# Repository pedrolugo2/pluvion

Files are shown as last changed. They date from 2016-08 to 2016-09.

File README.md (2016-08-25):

PLUVI.ON
--------

Como bons paulistanos, passamos pela mesma situação todos os anos. Chega dezembro, o céu escurece, a gente ouve um trovão lá no fundo, já dá aquele gelo na espinha pq a gente sabe que vem uma tempestade e provavelmente uma enchente por aí... E esse tipo de problema não acontece só em SP. 

Se olharmos Brasil, existem aproximadamente **30 milhões de brasileiros** expostos ao risco de enchentes e inundações. Além disso, existe uma projeção de impacto financeiro, onde as potenciais perdas anuais podem chegar a **4 bilhões de dólares até 2030** *(Fonte: Swiss Re)*

Olhando pra esse cenário alarmante, pensamos:
 “Vamos tentar resolver essa %$#@?” Se não para resolver totalmente, pelo menos entregar mais informação, mais inteligência para que a população possa se prevenir nesses eventos?
Resolvemos juntar nosso conhecimento de hardware e software e mergulhamos nesse mundo e logo de cara demos de cara com uma barreira: as dificuldades de conseguir informações sobre clima e chuva
Identificamos **3 principais desafios** relacionados à informação:

 1. As informações históricas são de difícil acesso ao cidadão comum (ou
    estão em mão de instituições privadas ou demandam muita burocracia
    dos órgãos públicos);
    
 2. Muitas delas são coletadas apenas no dia seguinte e portanto não auxiliam na
    prevenção 
    
 3. São informadas de forma genérica: “pode alagar a cidade de
    SP” – mas SP é grande demais para termos apenas essa informação. A
    probabilidade de alagar a Av. Paulista é sempre muito menor do que
    alagar a Av. Aricanduva

Foi a partir dessas hipóteses que construímos o Pluvi.On, uma estação meteorológica Open Source e de baixo custo para ser espalhada na maior quantidade de pontos da cidade que pudermos!!!

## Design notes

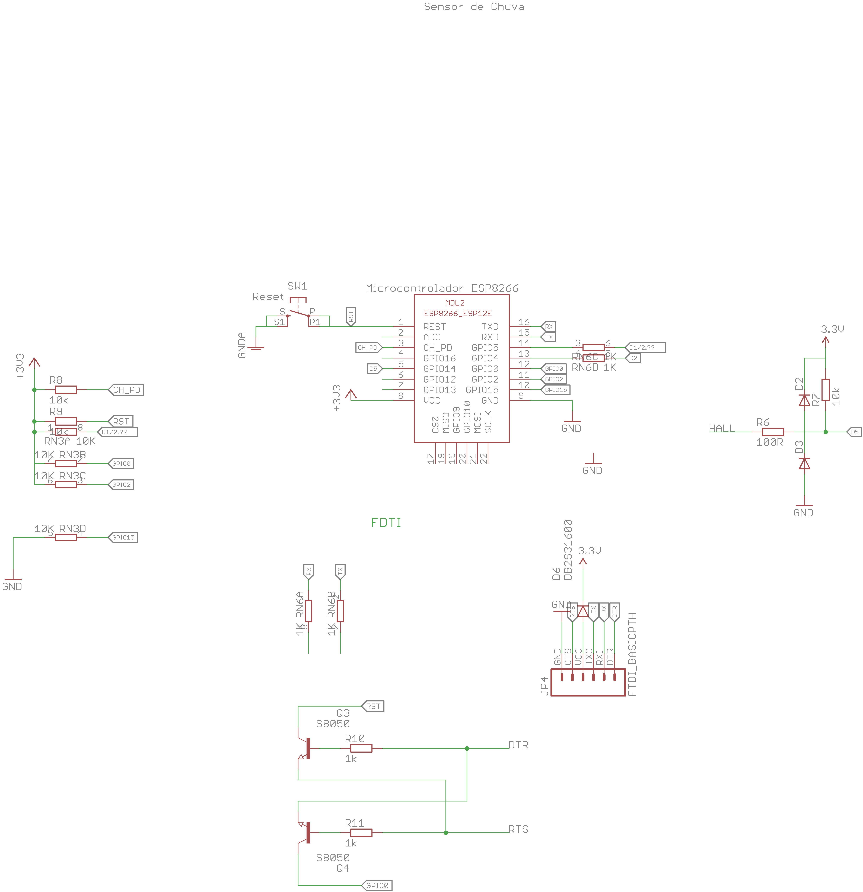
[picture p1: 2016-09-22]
Eletrônica/Principal/Pluvion 1 RevA_3.png

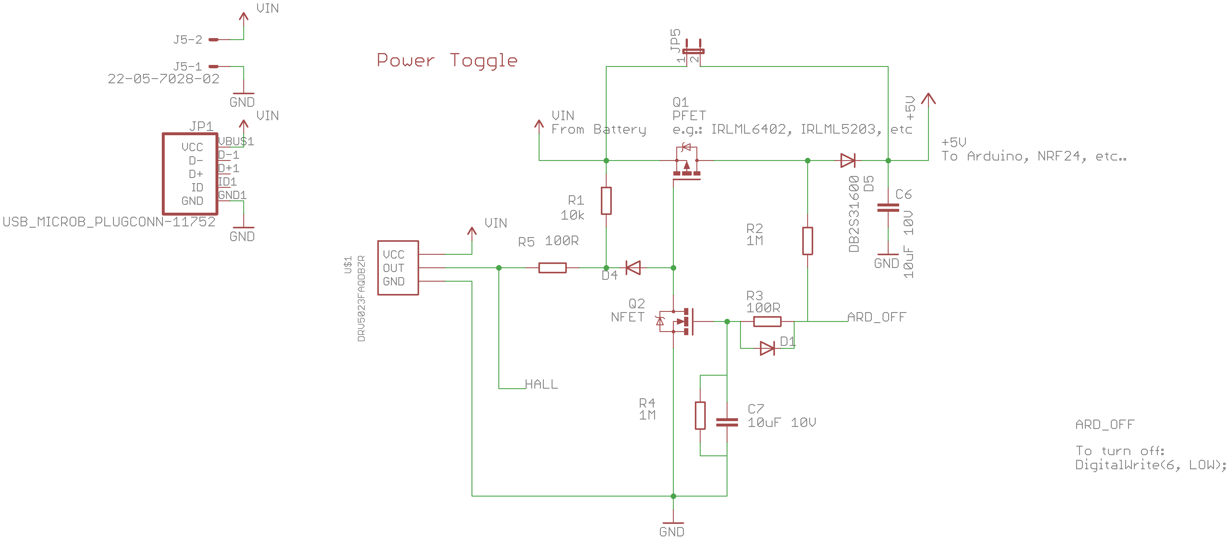
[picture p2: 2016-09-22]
Eletrônica/Principal/Pluvion 1 RevA_1.png

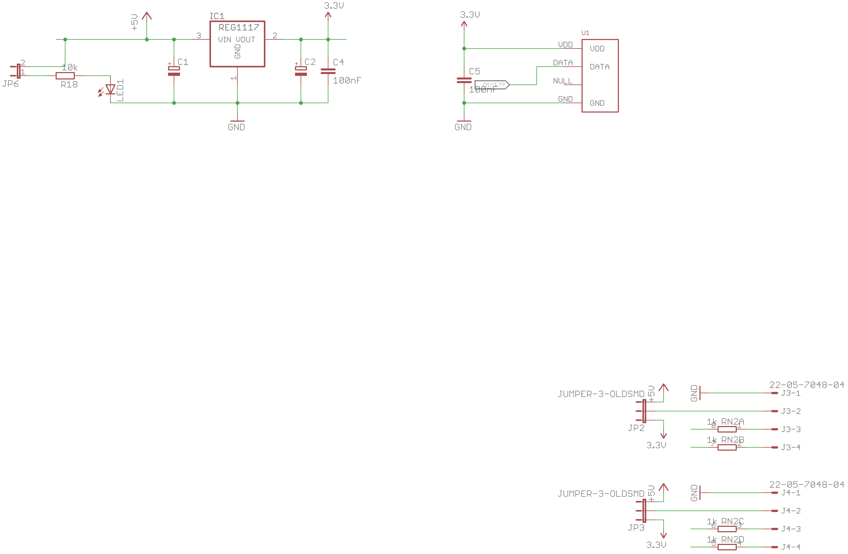
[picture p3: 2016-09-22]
Eletrônica/Principal/Pluvion 1 RevA_2.png

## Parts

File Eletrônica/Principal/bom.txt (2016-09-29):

Partlist exported from C:/Users/Pedro/Desktop/05. Krafty/XX. Projetos/Pluvi.On/residencia/Eletrônica/Principal/Pluvion 2.sch at 26/09/2016 10:45

Qty Value              Device                    Package            Parts      Description                   MF MPN OC_FARNELL OC_NEWARK PROD_ID    
2                      DIODESOD                  SOD-323            D1, D4     Diode                                                     DIO-09646  
1                      JUMPER-2PTH               1X02               JP5        Jumper                                                               
1                      R-EU_R0805                R0805              R6         RESISTOR, European symbol                                            
1                      RHT03_DHT-22_AM2302RA     RHT03_DHT-22/RA    U1         RHT03 / DHT-22 / AM2302                                   SEN-10167  
2   100R               R-EU_R0805                R0805              R3, R5     RESISTOR, European symbol                                            
1   10k                R-EU_R0805                R0805              R1         RESISTOR, European symbol                                            
3   10uF 10V           C-EUC0805                 C0805              C1, C6, C7 CAPACITOR, European symbol                                           
2   1M                 R-EU_R0805                R0805              R2, R4     RESISTOR, European symbol                                            
1   22-05-7028-02      22-05-7028-02             7395-02            J1         CONNECTOR                            9731601    unknown              
1   DB2S31600          DIODESMA                  SMA-DIODE          D5         Diode                                                                
1   DRV5023FAQDBZR     DRV5023FAQDBZR            SOT23              U$1        Digital Switch Hall Sensor                                           
1   NFET               MOSFET-NCHANNELBSS123LT1G SOT23              Q2         Common NMOSFET Parts                                      TRANS-08345
1   NODE-LOLIN-ESP8266 NODE-LOLIN-ESP8266        NODE-LOLIN-ESP8266 U$2                                                                             
1   PFET               IRLML5203                 MICRO3             Q1         HEXFET P-Channel Power MOSFET

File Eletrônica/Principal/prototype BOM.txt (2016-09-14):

Partlist exported from /Users/wes/Google Drive/trab/redbull/Residencia Basement/repo/Pluvion/Eletrônica/Principal/Pluvion 1 - Rev A.sch at 9/14/16 01:56

Assembly variant: ''

Qty Value                     Device                    Parts              
OK 2                             CPOL-EUC                  C1, C2             
OKISH 4                             DIODESOD                  D1, D2, D3, D4     
              
1                             JUMPER-2PTH               JP5                
                
1                             LED1206                   LED1               

1   1k                        4R-N0603-ARV              RN6, RN2   http://www.opoeneletronica.com.br/home/produto/codigo:12739/rede-resistiva-1k-0603-1608-smd-4res-superficie-rede-resistiva-5
1   10k                       4R-N0603-ARV              RN3    http://www.opoeneletronica.com.br/home/produto/codigo:12686/rede-resistiva-10k-0603-1608-smd-4res-superficie-rede-resistiva-5

OK 3   100R                      R-EU_R0805                R3, R5, R6
OK 2   1M                        R-EU_R0805                R2, R4    
OK 2   1k                        R-EU_R0805                R10, R11                          
OK 5   10k                       R-EU_R0805                R1, R7, R8, R9, R18

OK 2   10uF 10V                  C-EUC0805                 C6, C7 
OK 2   100nF                     C-EUC0805                 C4, C5

OK 2   DB2S31600                 DIODESMA                  D5, D6

1   DRV5023FAQDBZR            DRV5023FAQDBZR            U$1 

OK 1   NFET                      MOSFET-NCHANNELBSS123LT1G Q2                 
OK 1   PFET                      IRLML5203                 Q1                 
1   REG1117                   REG1117                   IC1  http://www.opoeneletronica.com.br/home/produto/codigo:14194/lm1117-3-3v-sot223-smd-superficie

1   Reset                     10-XX-4.5SMD              SW1 

OK 2   S8050                     NPN-TRANSISTOR_SOT23      Q3, Q4

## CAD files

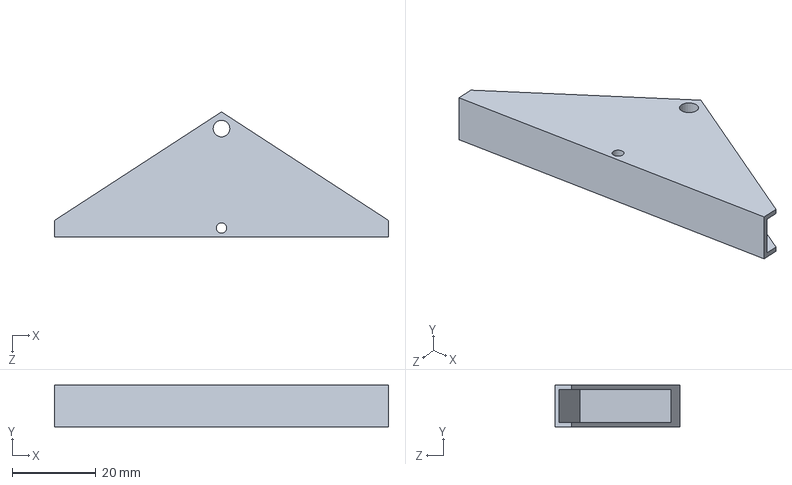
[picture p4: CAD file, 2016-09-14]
Mecânica/Bucket/Bucket.SLDPRT
80.0 x 10.0 x 30.0 mm

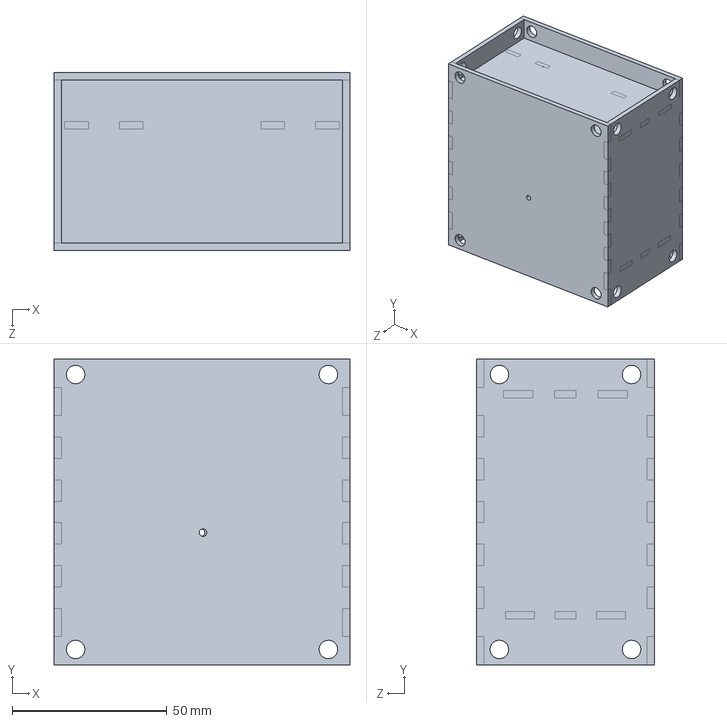
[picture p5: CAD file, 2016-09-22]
Mecânica/Montagem Pluvi.on - SW.SLDPRT
95.7 x 98.9 x 57.5 mm

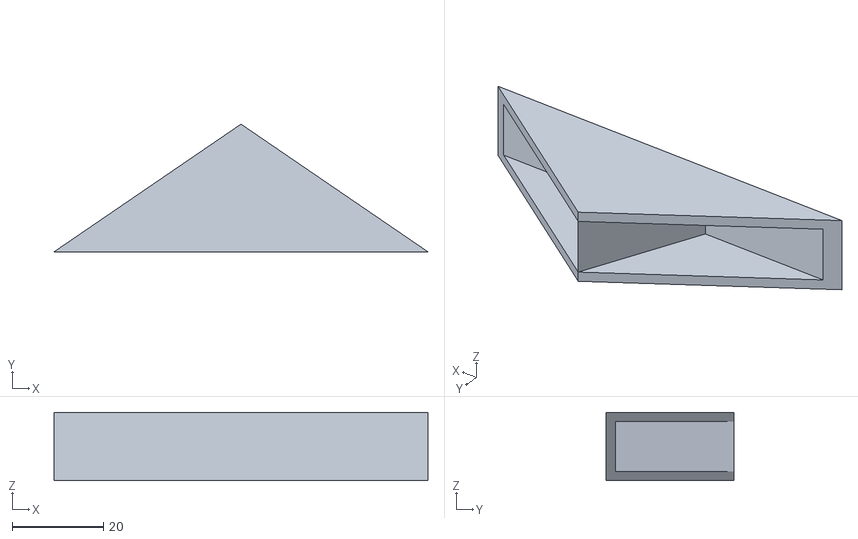
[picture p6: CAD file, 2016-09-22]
Mecânica/Pluvi.on - Triangulo volume stl.STL
82.0 x 28.0 x 15.0

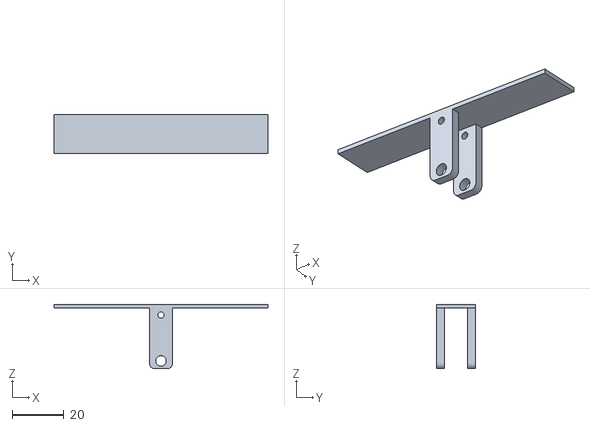
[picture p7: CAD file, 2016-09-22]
Mecânica/Base.stl
83.0 x 15.0 x 25.0

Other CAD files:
Mecânica/Bucket/Bucket.STL
Mecânica/Montagem Pluvi.on - SW.STL

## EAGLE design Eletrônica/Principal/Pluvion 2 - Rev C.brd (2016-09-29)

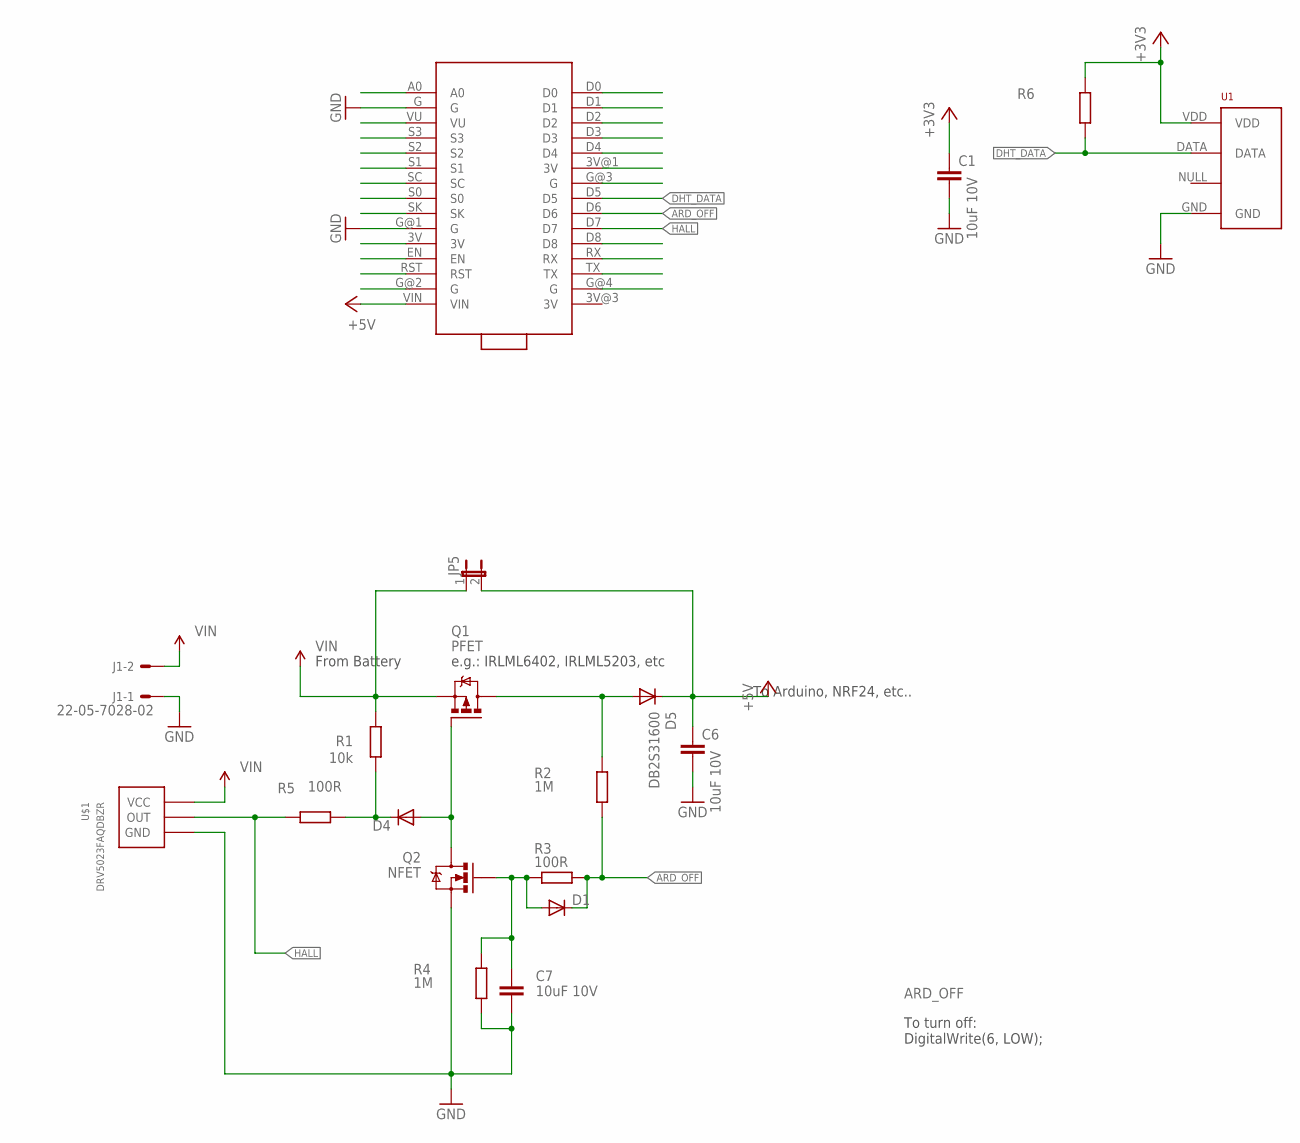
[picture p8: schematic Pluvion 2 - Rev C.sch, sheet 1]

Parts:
C1, C6, C7: 10uF 10V; C0805
D1, D4: DIODESOD; SOD-323
D5: DB2S31600; SMA-DIODE
J1: 22-05-7028-02; 7395-02
JP5: JUMPER-2PTH; 1X02
Q1: PFET; MICRO3
Q2: NFET; SOT23
R1: 10k; R0805
R2, R4: 1M; R0805
R3, R5: 100R; R0805
R6: R-EU_R0805; R0805
U1: RHT03_DHT-22_AM2302RA; RHT03_DHT-22/RA
U$1: DRV5023FAQDBZR; SOT23
U$2: NODE-LOLIN-ESP8266

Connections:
+3V3: C1.1, R6.2, U1.VDD, U$2.3V@1 (3V)
+5V: C6.1, D5.C, JP5.2, U$2.VIN
ARD_OFF: D1.1 (C), R2.1, R3.2, U$2.D6
BUTTONS: D4.2 (A), Q1.1 (G), Q2.3 (D)
DHT_DATA: R6.1, U1.DATA, U$2.D5
GND: C1.2, C6.2, C7.2, J1.1, Q2.2 (S), R4.1, U1.GND, U$1.3 (GND), U$2.G, U$2.G@1 (G)
HALL: R5.2, U$1.2 (OUT), U$2.D7
unnamed: D5.A, Q1.3 (D), R2.2
unnamed: C7.1, D1.2 (A), Q2.1 (G), R3.1, R4.2
unnamed: D4.1 (C), R1.1, R5.1
VIN: J1.2, JP5.1, Q1.2 (S), R1.2, U$1.1 (VCC)

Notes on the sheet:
e.g.: IRLML6402, IRLML5203, etc
To Arduino, NRF24, etc..
To turn off: DigitalWrite(6, LOW);
From Battery

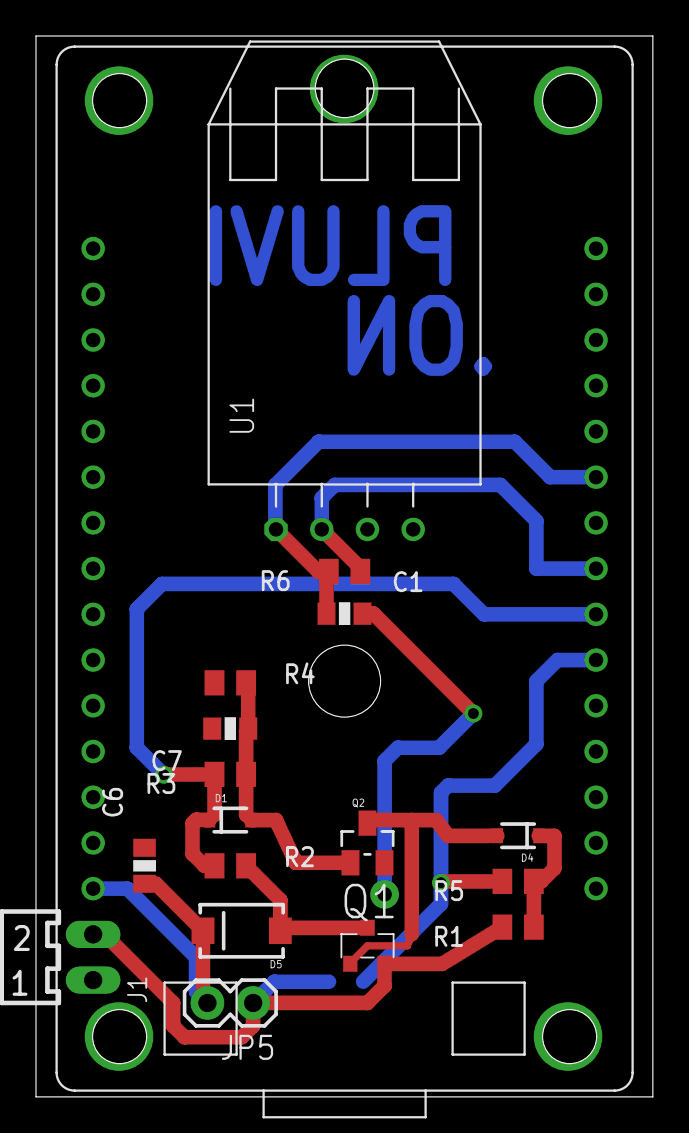
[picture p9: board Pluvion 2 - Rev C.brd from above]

Board: 2 copper layers, 34.3 x 58.9 mm, 19 parts (1 on the bottom side), 11 nets.

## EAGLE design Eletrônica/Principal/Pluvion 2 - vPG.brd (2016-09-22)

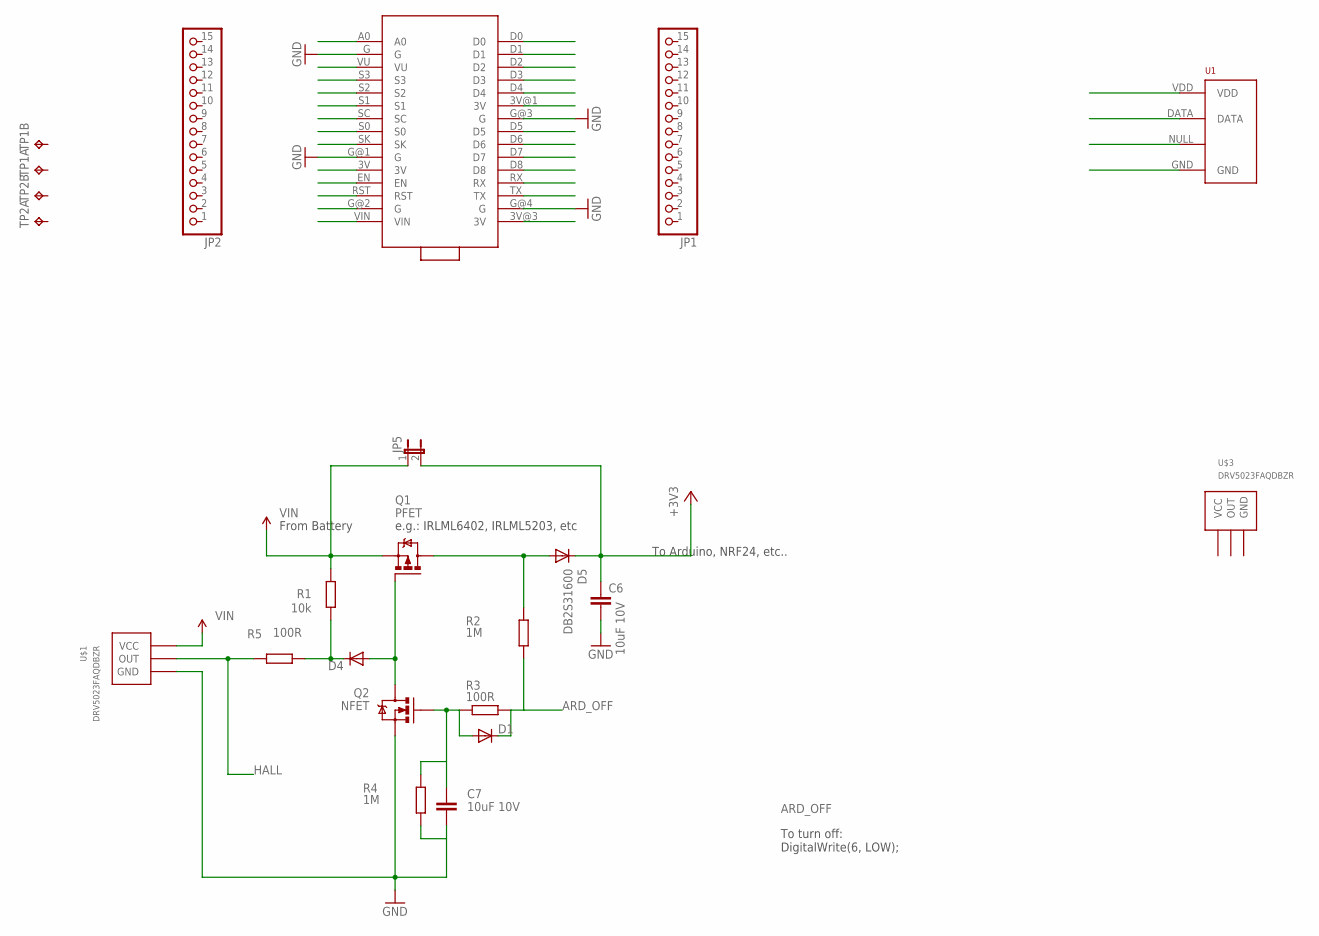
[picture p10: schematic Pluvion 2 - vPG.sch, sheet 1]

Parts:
C6, C7: 10uF 10V; C0805
D1, D4: DIODESMB; SMB-DIODE
D5: DB2S31600; SMB-DIODE
JP1, JP2: PINHD-1X15; 1X15
JP5: JUMPER-2PTH; 1X02
Q1: PFET; MICRO3
Q2: NFET; SOT23
R1: 10k; R0805
R2, R4: 1M; R0805
R3, R5: 100R; R0805
TP1, TP2: TP2P2-38-17; P2-38-17
U1: RHT03_DHT-22_AM2302RA; RHT03_DHT-22/RA
U$1, U$3: DRV5023FAQDBZR; SOT23
U$2: NODE-LOLIN-ESP8266

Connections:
+3V3: C6.1, D5.C, JP5.2
ARD_OFF: D1.C, R2.1, R3.2
BUTTONS: D4.A, Q1.1 (G), Q2.3 (D)
GND: C6.2, C7.2, Q2.2 (S), R4.1, U$1.3 (GND), U$2.G, U$2.G@1 (G), U$2.G@3 (G), U$2.G@4 (G)
HALL: R5.2, U$1.2 (OUT)
unnamed: D5.A, Q1.3 (D), R2.2
unnamed: C7.1, D1.A, Q2.1 (G), R3.1, R4.2
unnamed: D4.C, R1.1, R5.1
VIN: JP5.1, Q1.2 (S), R1.2, U$1.1 (VCC)

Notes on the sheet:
e.g.: IRLML6402, IRLML5203, etc
To Arduino, NRF24, etc..
To turn off: DigitalWrite(6, LOW);
From Battery

Board: 2 copper layers, 21 parts (0 on the bottom side), 9 nets, no tracks yet.

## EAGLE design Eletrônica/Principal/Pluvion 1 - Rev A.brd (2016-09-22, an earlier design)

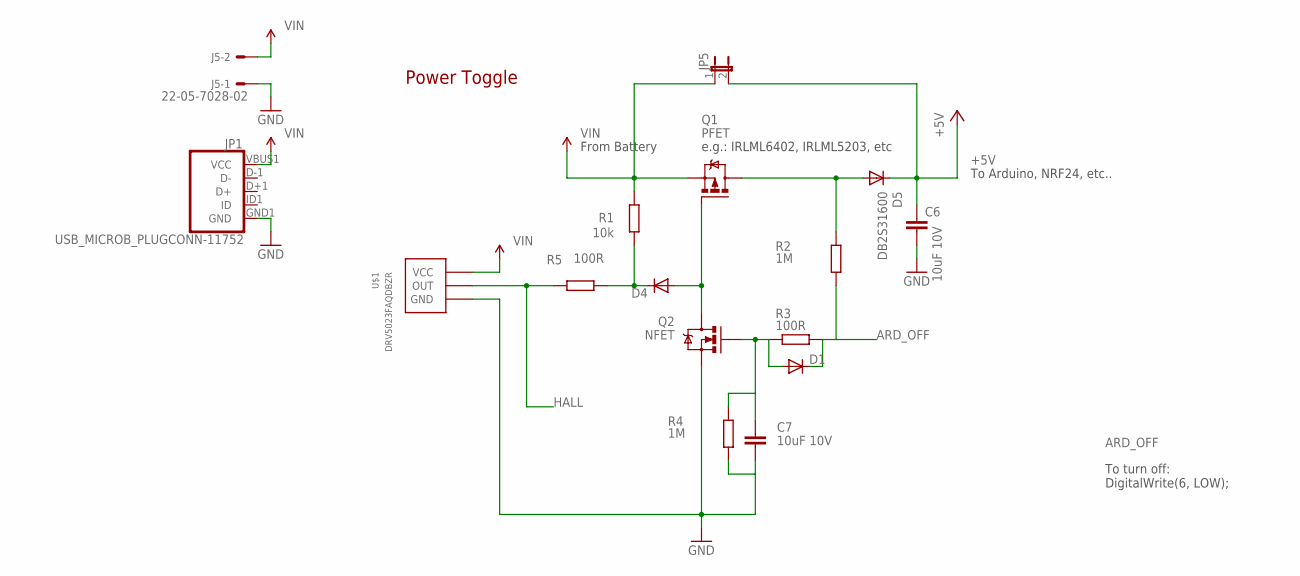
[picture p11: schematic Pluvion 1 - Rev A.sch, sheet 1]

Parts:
C6, C7: 10uF 10V; C0805
D1, D4: DIODESOD; SOD-323
D5: DB2S31600; SMA-DIODE
J5: 22-05-7028-02; 7395-02
JP1: USB_MICROB_PLUGCONN-11752; USB-B-MICRO-SMD_V03
JP5: JUMPER-2PTH; 1X02
Q1: PFET; MICRO3
Q2: NFET; SOT23
R1: 10k; R0805
R2, R4: 1M; R0805
R3, R5: 100R; R0805
U$1: DRV5023FAQDBZR; SOT23

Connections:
+5V: C6.1, D5.C, JP5.2; also elsewhere on the board
ARD_OFF: D1.1 (C), R2.1, R3.2
BUTTONS: D4.2 (A), Q1.1 (G), Q2.3 (D)
GND: C6.2, C7.2, J5.1, JP1.GND1 (GND), Q2.2 (S), R4.1, U$1.3 (GND); also elsewhere on the board
HALL: R5.2, U$1.2 (OUT); also elsewhere on the board
unnamed: D5.A, Q1.3 (D), R2.2
unnamed: C7.1, D1.2 (A), Q2.1 (G), R3.1, R4.2
unnamed: D4.1 (C), R1.1, R5.1
VIN: J5.2, JP1.VBUS1 (VCC), JP5.1, Q1.2 (S), R1.2, U$1.1 (VCC)

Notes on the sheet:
e.g.: IRLML6402, IRLML5203, etc
To Arduino, NRF24, etc..
To turn off: DigitalWrite(6, LOW);
From Battery
Power Toggle

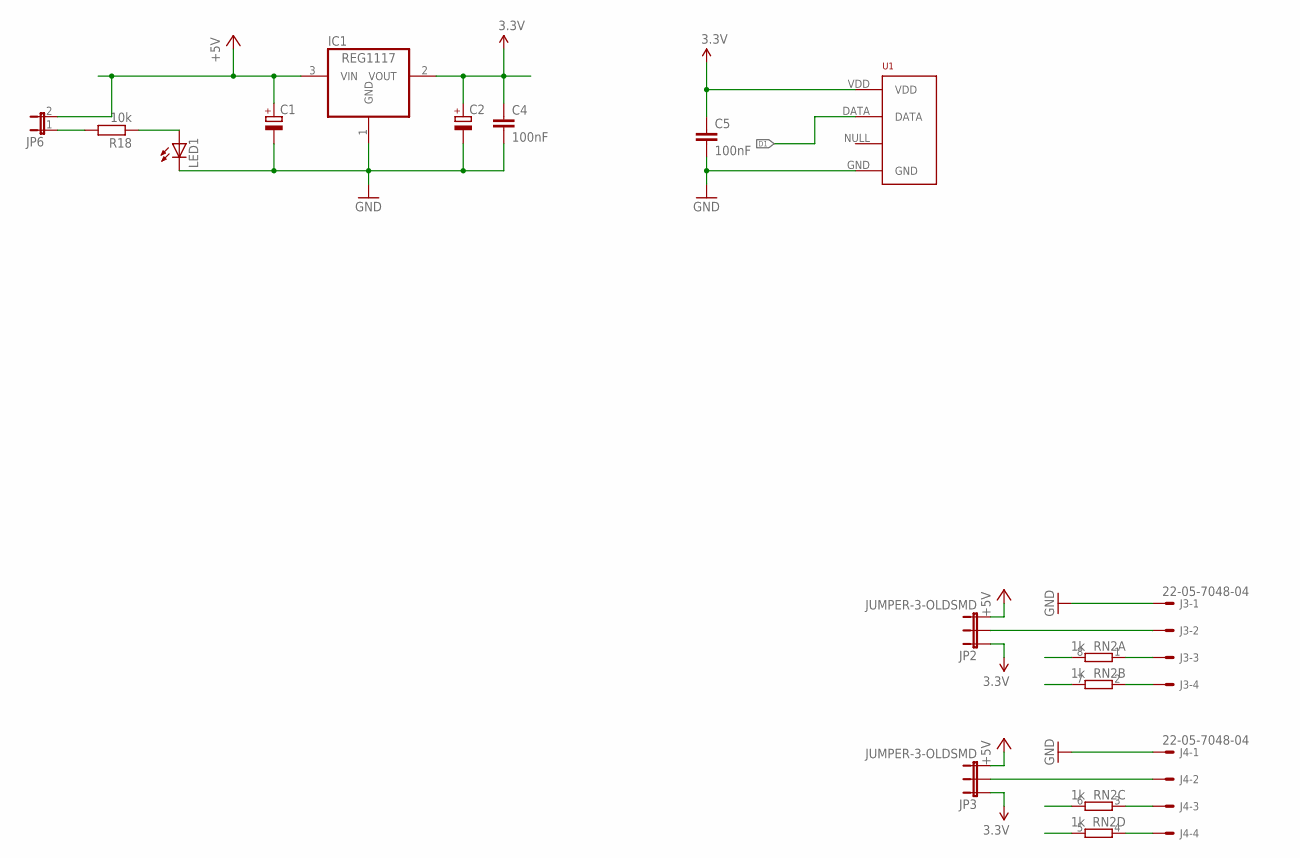
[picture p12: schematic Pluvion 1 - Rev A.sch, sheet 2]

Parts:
C1, C2: CPOL-EUC; PANASONIC_C
C4, C5: 100nF; C0805
IC1: REG1117; SOT223
J3, J4: 22-05-7048-04; 7395-04
JP2, JP3: JUMPER-3-OLDSMD; SJ_3
JP6: JUMPER-2SMD-NO; SJ_2S-NO
LED1: LED1206; LED-1206
R18: 10k; R0805
RN2: 1k; 0603-ARV
U1: RHT03_DHT-22_AM2302RA; RHT03_DHT-22/RA

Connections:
+3V3: C2.+, C4.1, C5.1, IC1.2 (VOUT), JP2.1, JP3.1, U1.VDD; also elsewhere on the board
+5V: C1.+, IC1.3 (VIN), JP2.3, JP3.3, JP6.2; also elsewhere on the board
D1: U1.DATA; also elsewhere on the board
GND: C1.-, C2.-, C4.2, C5.2, IC1.1 (GND), J3.1, J4.1, LED1.C, U1.GND; also elsewhere on the board
unnamed: J3.3, RN2.1
unnamed: J3.4, RN2.2 (1)
unnamed: J4.3, RN2.3 (1)
unnamed: J3.2, JP2.2
unnamed: J4.4, RN2.4 (1)
unnamed: J4.2, JP3.2
unnamed: LED1.A, R18.1
unnamed: JP6.1, R18.2

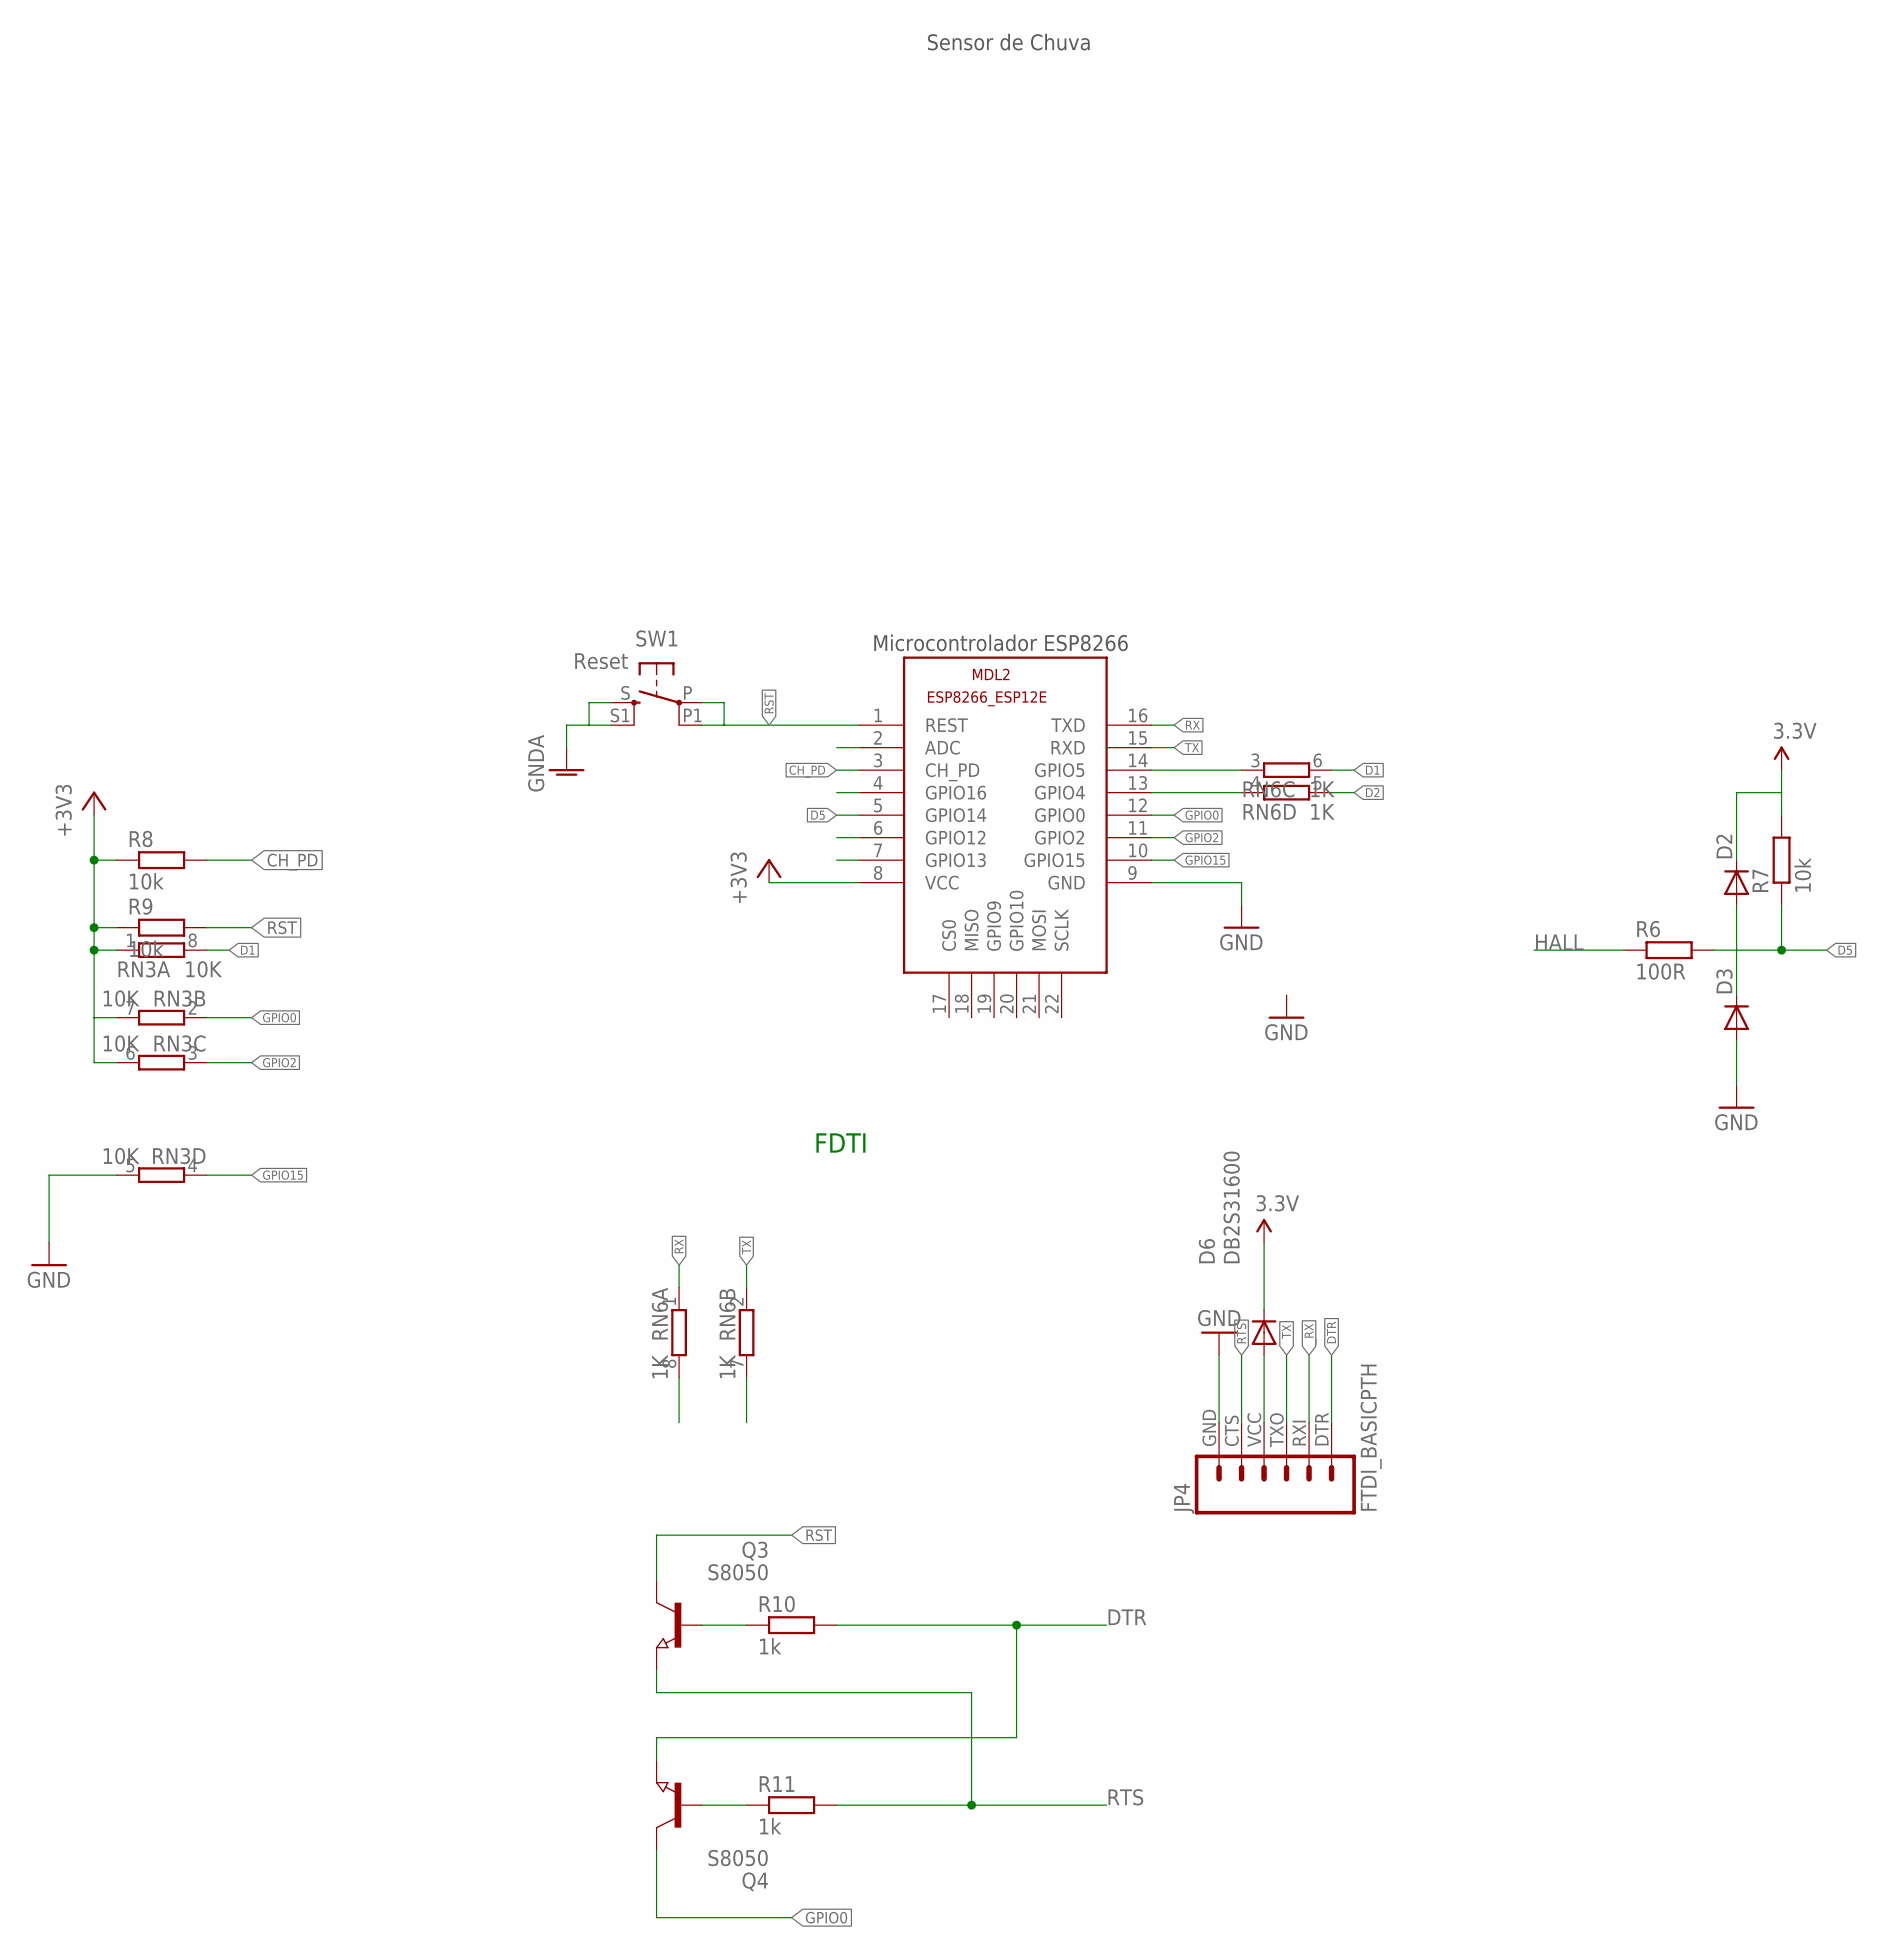
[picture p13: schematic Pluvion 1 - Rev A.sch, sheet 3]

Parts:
D2, D3: DIODESOD; SOD-323
D6: DB2S31600; SMA-DIODE
JP4: FTDI_BASICPTH; FTDI_BASIC
MDL2: ESP8266-12EESP8266-ESP12E; ESP8266-ESP12E
Q3, Q4: S8050; SOT23
R6: 100R; R0805
R7, R8, R9: 10k; R0805
R10, R11: 1k; R0805
RN3: 10K; 0603-ARV
RN6: 1K; 0603-ARV
SW1: Reset; BT4.5X4.5

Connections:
+3V3: D2.1 (C), D6.C, MDL2.8 (VCC), R7.2, R8.1, R9.1, RN3.1, RN3.6 (2), RN3.7 (2); also elsewhere on the board
CH_PD: MDL2.3 (CH_PD), R8.2
D1: RN3.8 (2), RN6.6 (2); also elsewhere on the board
D2: RN6.5 (2)
D5: D2.2 (A), D3.1 (C), MDL2.5 (GPIO14), R6.2, R7.1
DTR: JP4.DTR (1), Q4.2 (E), R10.2
GND: D3.2 (A), JP4.GND (6), MDL2.9 (GND), RN3.5 (2), SW1.S, SW1.S1; also elsewhere on the board
GPIO0: MDL2.12 (GPIO0), Q4.3 (C), RN3.2 (1)
GPIO2: MDL2.11 (GPIO2), RN3.3 (1)
GPIO15: MDL2.10 (GPIO15), RN3.4 (1)
HALL: R6.1; also elsewhere on the board
unnamed: Q3.1 (B), R10.1
unnamed: Q4.1 (B), R11.1
unnamed: MDL2.14 (GPIO5), RN6.3 (1)
unnamed: D6.A, JP4.VCC (4)
unnamed: MDL2.13 (GPIO4), RN6.4 (1)
RST: MDL2.1 (REST), Q3.3 (C), R9.2, SW1.P, SW1.P1
RTS: JP4.CTS (5), Q3.2 (E), R11.2
RX: MDL2.16 (TXD), RN6.1
TX: MDL2.15 (RXD), RN6.2 (1)
_RX: JP4.RXI (2), RN6.8 (2)
_TX: JP4.TXO (3), RN6.7 (2)

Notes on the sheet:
Sensor de Chuva
Microcontrolador ESP8266
FDTI

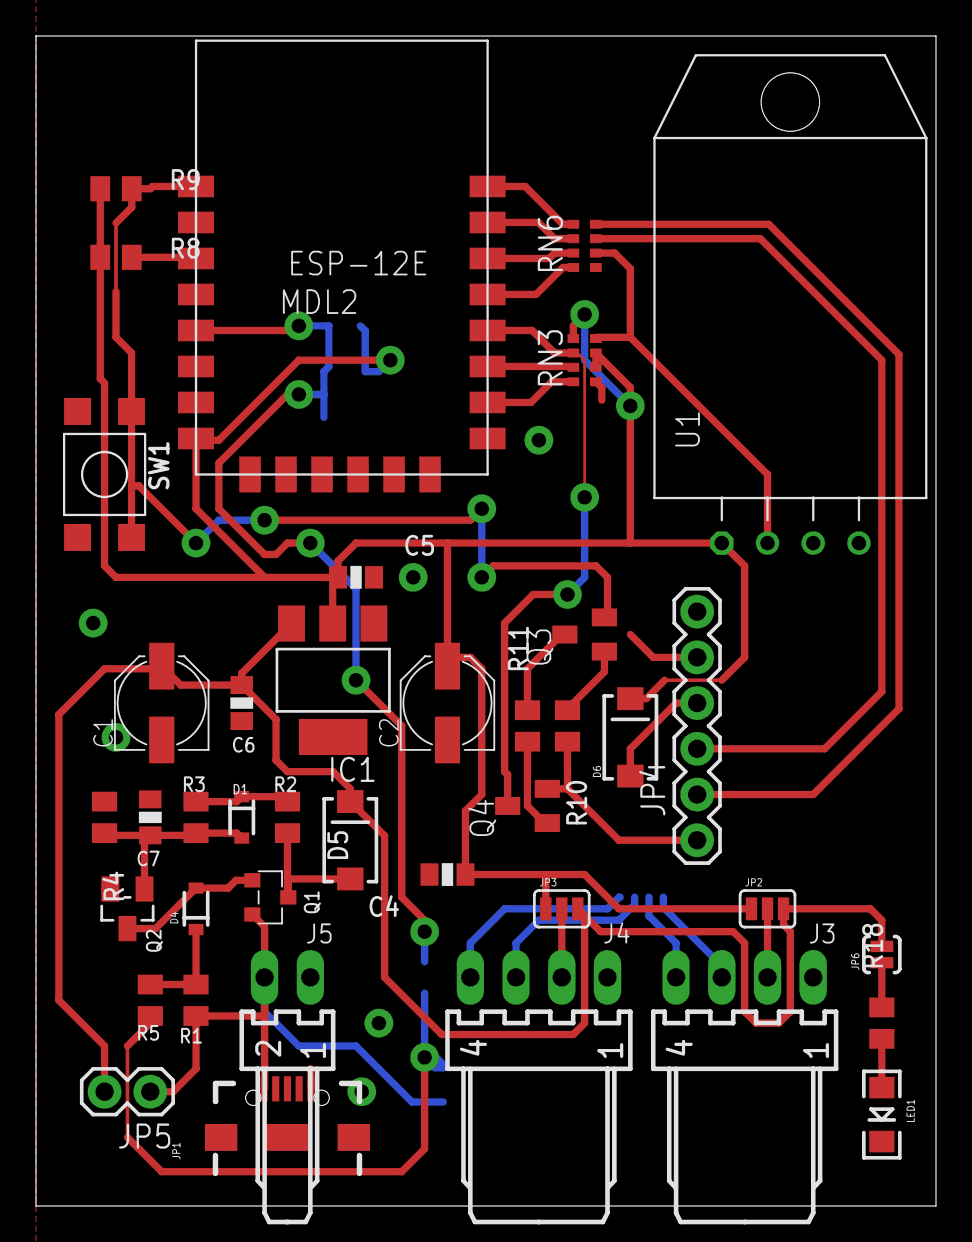
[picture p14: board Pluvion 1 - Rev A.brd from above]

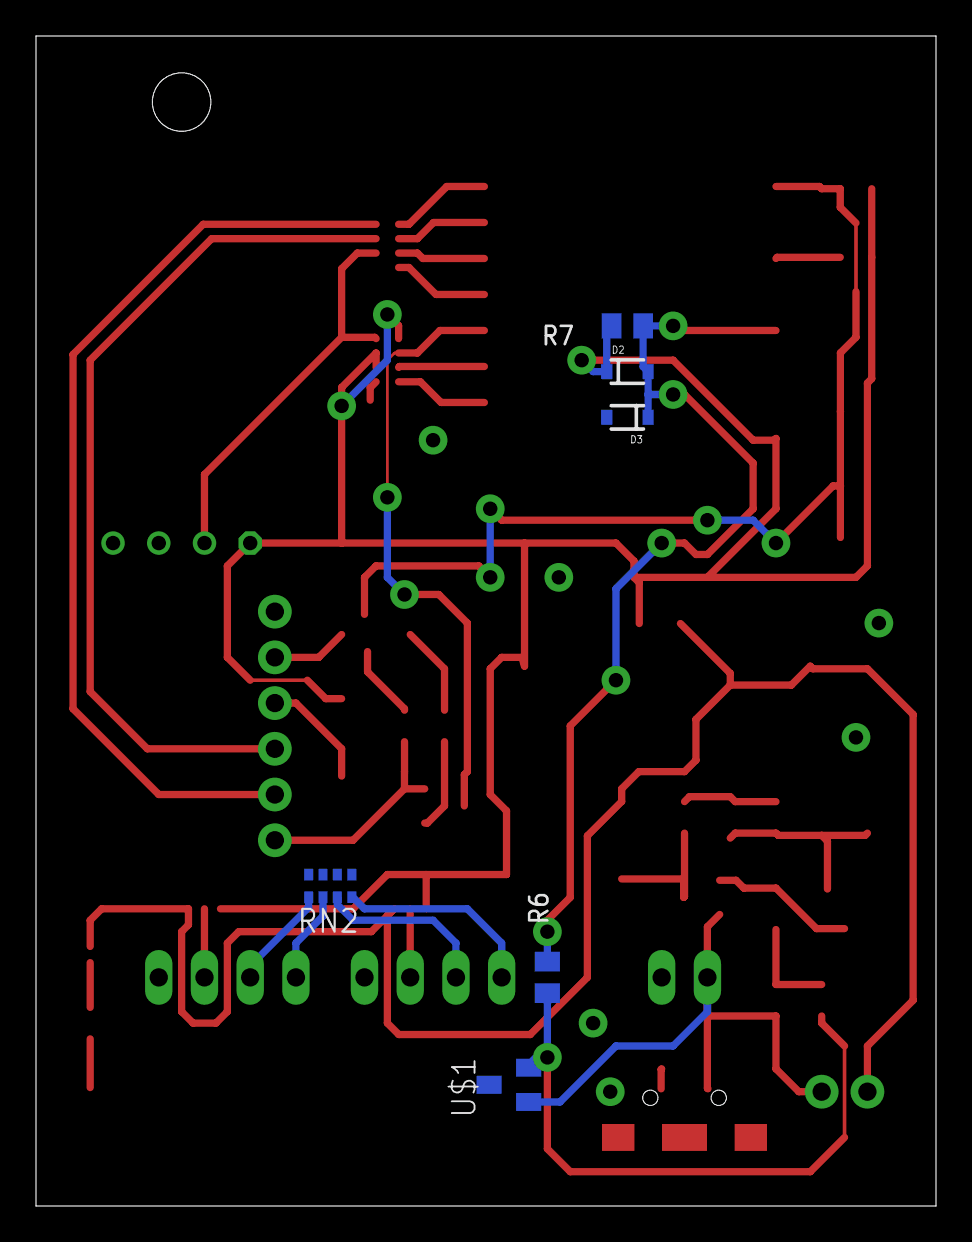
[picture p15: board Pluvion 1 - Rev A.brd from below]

Board: 2 copper layers, 50.0 x 65.0 mm, 46 parts (6 on the bottom side), 36 nets.

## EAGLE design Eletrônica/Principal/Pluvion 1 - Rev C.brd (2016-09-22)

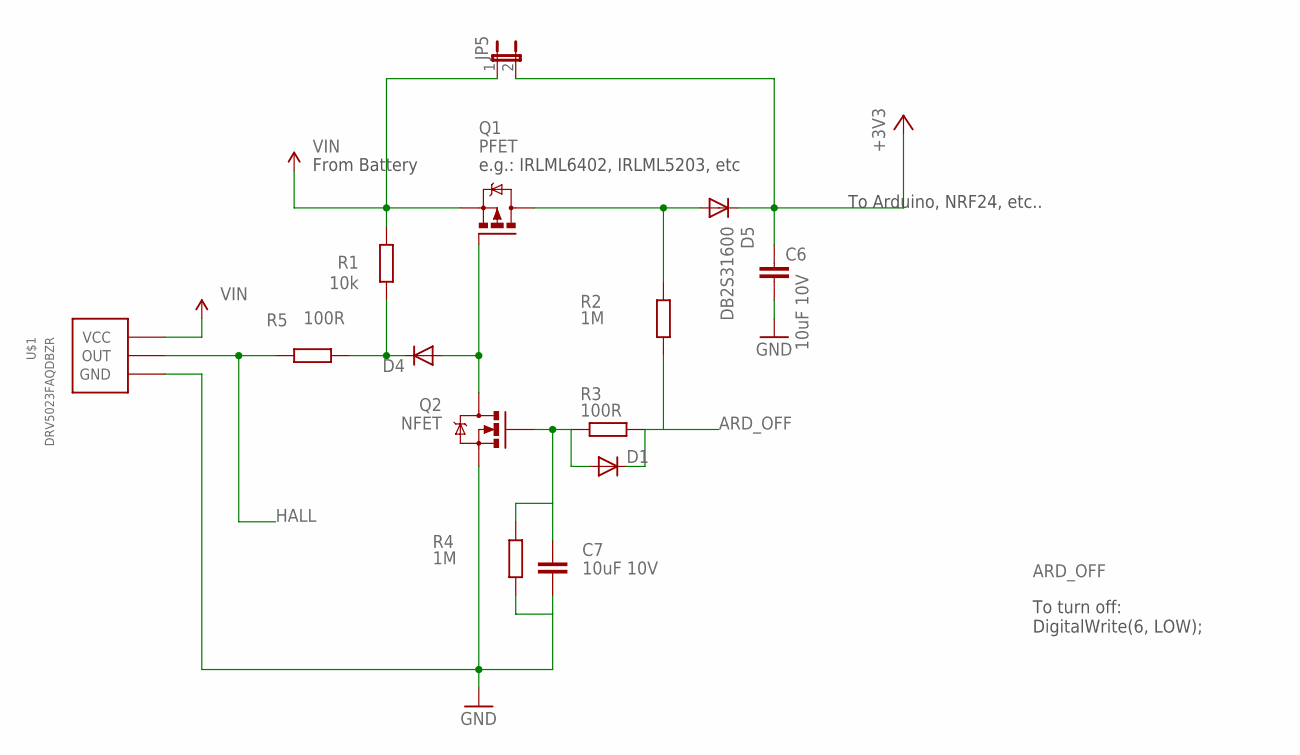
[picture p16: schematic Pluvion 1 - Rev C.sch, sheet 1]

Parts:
C6, C7: 10uF 10V; C0805
D1, D4: DIODESMB; SMB-DIODE
D5: DB2S31600; SMB-DIODE
JP5: JUMPER-2PTH; 1X02
Q1: PFET; MICRO3
Q2: NFET; SOT23
R1: 10k; R0805
R2, R4: 1M; R0805
R3, R5: 100R; R0805
U$1: DRV5023FAQDBZR; SOT23

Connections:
+3V3: C6.1, D5.C, JP5.2; also elsewhere on the board
ARD_OFF: D1.C, R2.1, R3.2; also elsewhere on the board
BUTTONS: D4.A, Q1.1 (G), Q2.3 (D)
GND: C6.2, C7.2, Q2.2 (S), R4.1, U$1.3 (GND); also elsewhere on the board
HALL: R5.2, U$1.2 (OUT)
unnamed: D5.A, Q1.3 (D), R2.2
unnamed: C7.1, D1.A, Q2.1 (G), R3.1, R4.2
unnamed: D4.C, R1.1, R5.1
VIN: JP5.1, Q1.2 (S), R1.2, U$1.1 (VCC)

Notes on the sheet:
e.g.: IRLML6402, IRLML5203, etc
To Arduino, NRF24, etc..
To turn off: DigitalWrite(6, LOW);
From Battery

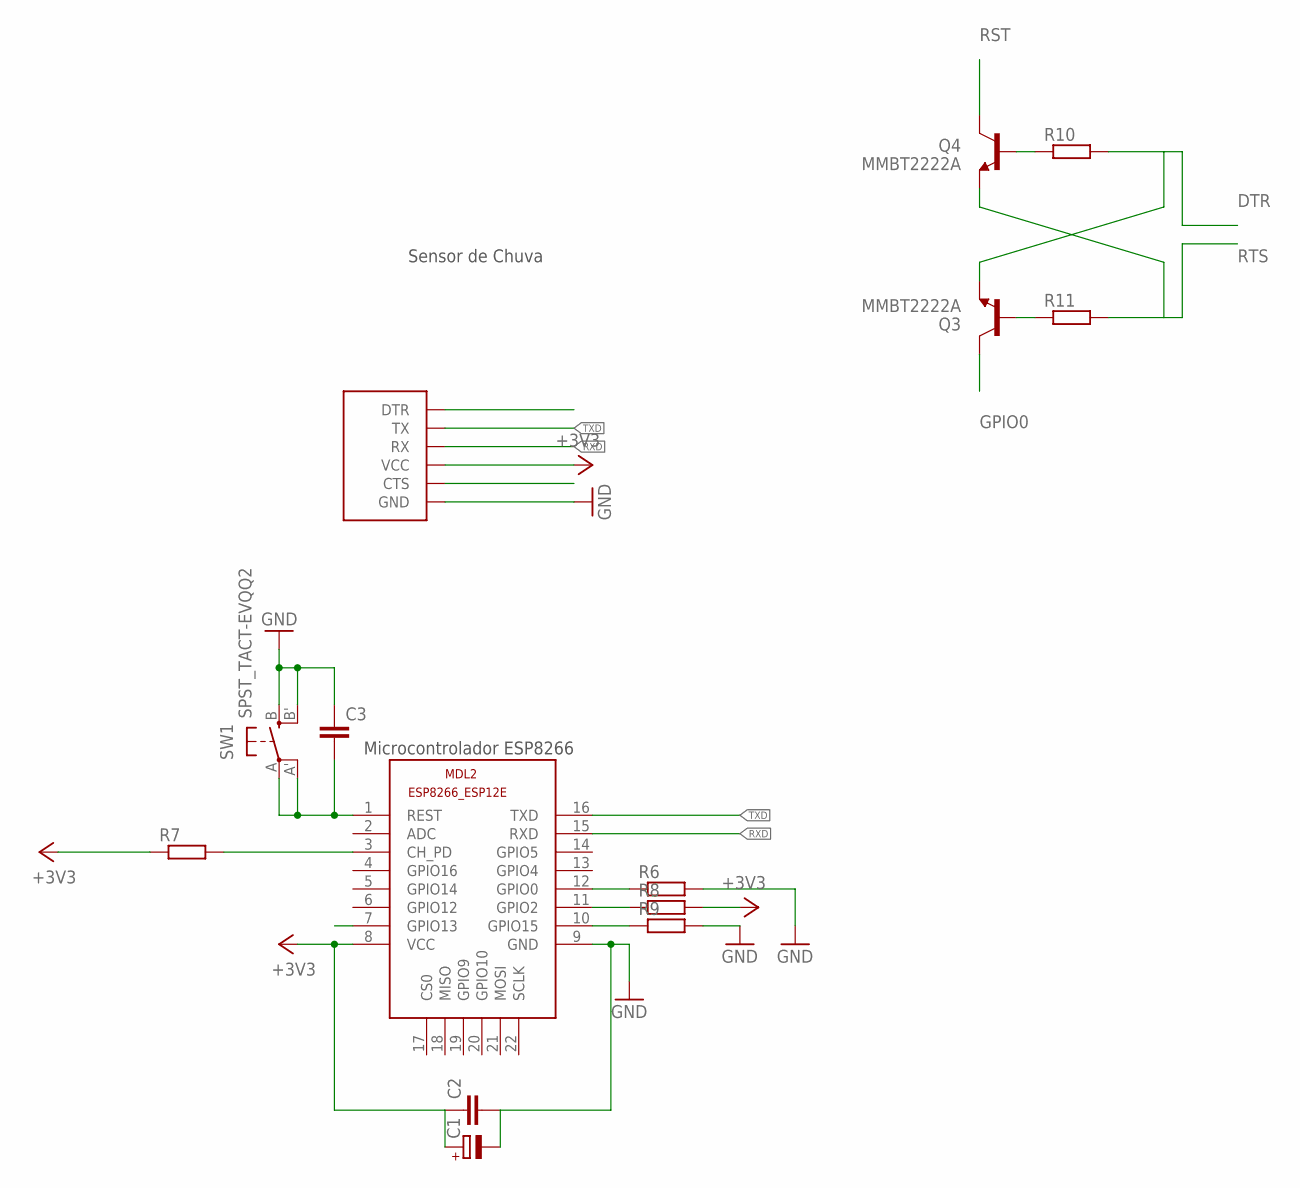
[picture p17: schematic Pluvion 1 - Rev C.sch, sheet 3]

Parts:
C1: CPOL-EUC; PANASONIC_C
C2, C3: C-EUC0805; C0805
MDL2: ESP8266-12EESP8266-ESP12E; ESP8266-ESP12E
Q3, Q4: MMBT2222A; SOT23
R6, R7, R8, R9, R10, R11: R-EU_R0805; R0805
SW1: SPST_TACT-EVQQ2; EVQ-Q2
U$2: FTDI_HEADERSMD; FTDI_HEADER_SMD

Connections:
+3V3: C1.+, C2.1, MDL2.8 (VCC), R7.1, R8.2, U$2.VCC; also elsewhere on the board
ARD_OFF: MDL2.7 (GPIO13); also elsewhere on the board
DTR: Q3.2 (E), R10.2, U$2.DTR
GND: C1.-, C2.2, C3.1, MDL2.9 (GND), R6.2, R9.2, SW1.B (S), SW1.B' (S1), U$2.GND; also elsewhere on the board
GPIO0: MDL2.12 (GPIO0), Q3.3 (C), R6.1
unnamed: C3.2, MDL2.1 (REST), SW1.A, SW1.A' (P1)
unnamed: MDL2.3 (CH_PD), R7.2
unnamed: MDL2.11 (GPIO2), R8.1
unnamed: MDL2.10 (GPIO15), R9.1
unnamed: Q3.1 (B), R11.1
unnamed: Q4.1 (B), R10.1
RST: Q4.3 (C)
RTS: Q4.2 (E), R11.2, U$2.CTS
RXD: MDL2.15 (RXD), U$2.RX
TXD: MDL2.16 (TXD), U$2.TX

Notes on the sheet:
Sensor de Chuva
Microcontrolador ESP8266

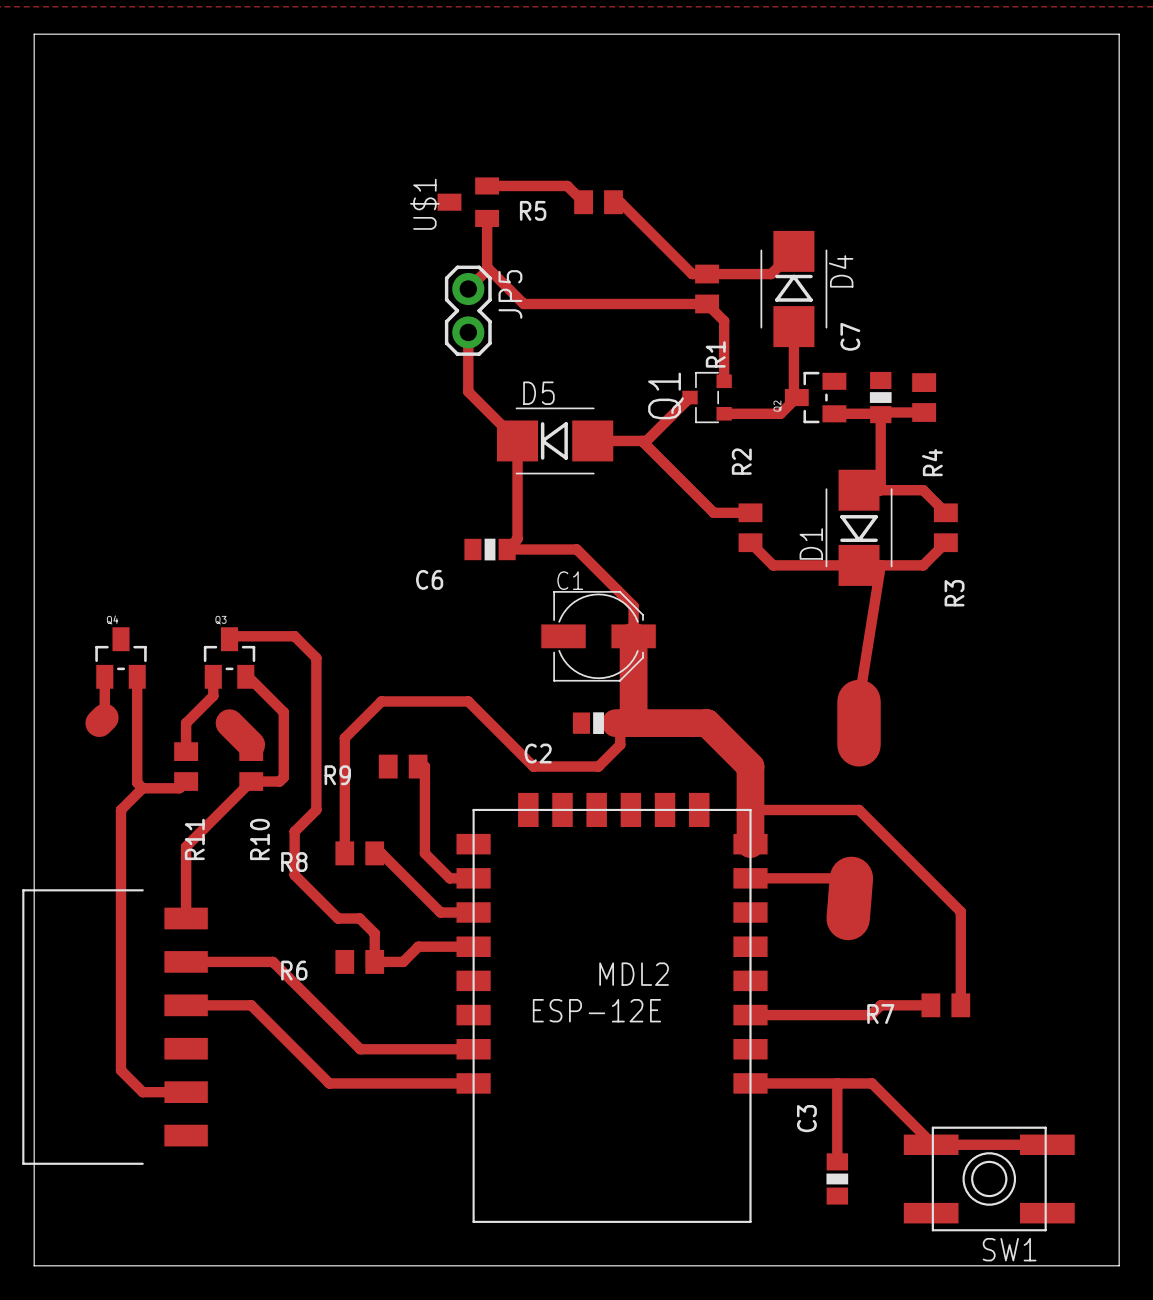
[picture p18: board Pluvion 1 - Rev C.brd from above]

Board: 2 copper layers, 63.5 x 72.1 mm, 28 parts (0 on the bottom side), 20 nets.

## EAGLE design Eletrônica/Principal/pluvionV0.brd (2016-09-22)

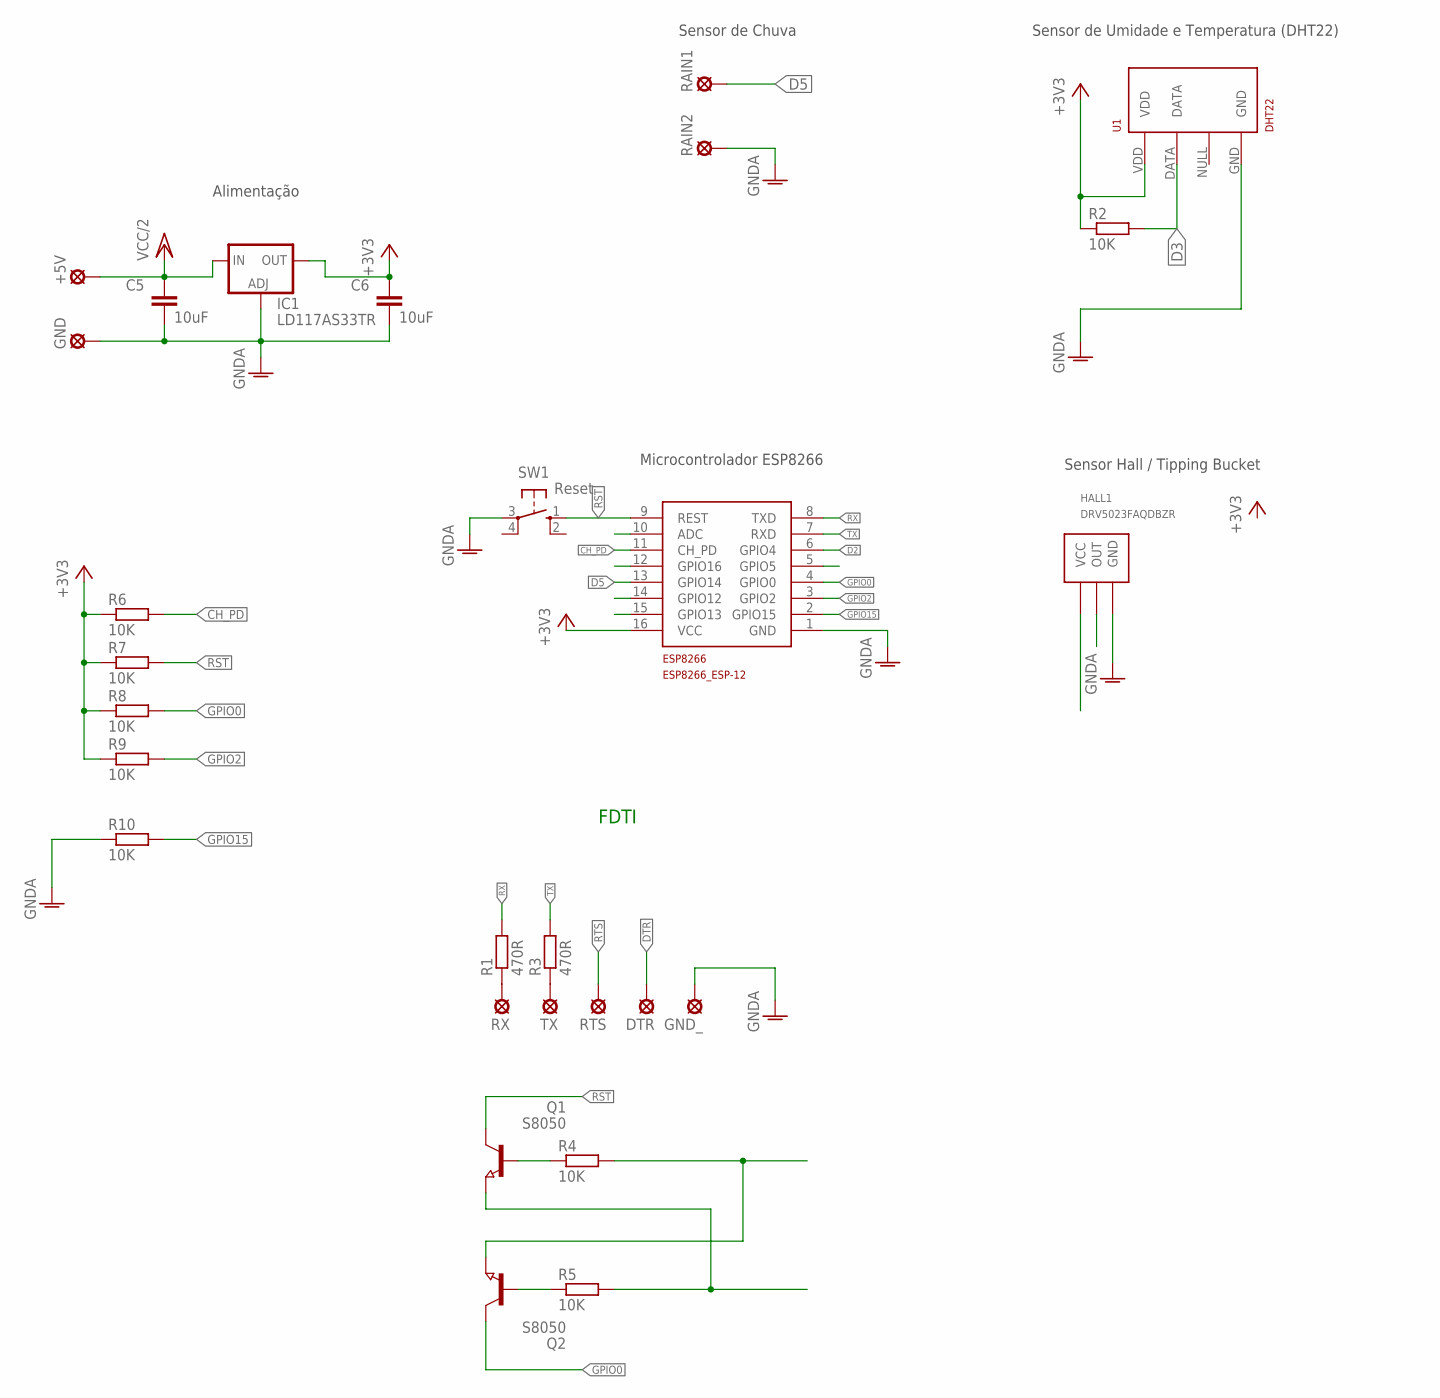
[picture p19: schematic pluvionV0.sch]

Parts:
+5V: LSP10
C5, C6: 10uF; C0805K
DTR: LSP10
ESP8266: ESP8266_ESP-12; ESP8266-ESP12
GND: LSP10
GND_: LSP10
HALL1: DRV5023FAQDBZR; SOT23
IC1: LD117AS33TR; SOT223
Q1, Q2: S8050; SOT23
R1, R3: 470R; M1206
R2, R4, R5, R6, R7, R8, R9, R10: 10K; M1206
RAIN1, RAIN2: LSP10
RTS: LSP10
RX: LSP10
SW1: Reset; B3F-10XX
TX: LSP10
U1: DHT22; RHT03_DHT-22/RA

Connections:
+3V3: C6.1, ESP8266.16 (VCC), IC1.4 (OUT), R2.1, R6.1, R7.1, R8.1, R9.1, U1.VDD
CH_PD: ESP8266.11 (CH_PD), R6.2
D2: ESP8266.6 (GPIO4)
D3: R2.2, U1.DATA
D5: ESP8266.13 (GPIO14), RAIN1.MP
DTR: DTR.MP, Q2.2 (E), R4.2
GND: C5.2, C6.2, ESP8266.1 (GND), GND.MP, IC1.1 (ADJ), RAIN2.MP, SW1.3, U1.GND
GNDA: GND_.MP, HALL1.3 (GND), R10.1
GPIO0: ESP8266.4 (GPIO0), Q2.3 (C), R8.2
GPIO2: ESP8266.3 (GPIO2), R9.2
GPIO15: ESP8266.2 (GPIO15), R10.2
unnamed: R1.1, RX.MP
unnamed: Q1.1 (B), R4.1
unnamed: R3.1, TX.MP
unnamed: Q2.1 (B), R5.1
RST: ESP8266.9 (REST), Q1.3 (C), R7.2, SW1.1 (S)
RTS: Q1.2 (E), R5.2, RTS.MP
RX: ESP8266.8 (TXD), R1.2
TX: ESP8266.7 (RXD), R3.2
VCC/2: +5V.MP, C5.1, IC1.3 (IN)

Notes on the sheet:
Sensor de Umidade e Temperatura (DHT22)
Sensor Hall / Tipping Bucket
Sensor de Chuva
Microcontrolador ESP8266
Alimentação
FDTI

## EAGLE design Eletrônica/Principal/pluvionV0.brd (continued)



Board: 2 copper layers, 47.3 x 80.0 mm, 28 parts (2 on the bottom side), 19 nets.

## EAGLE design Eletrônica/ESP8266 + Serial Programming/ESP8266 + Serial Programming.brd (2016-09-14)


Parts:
DTR: LSP10
GND_: LSP10
MDL1: ESP8266-12EESP8266-ESP12E; ESP8266-ESP12E
Q1, Q2: S8050; SOT23
R1, R2, R3, R4, R6, R7, R8, R9, R10: R-EU_R0805; R0805
RAIN1, RAIN2: LSP10
RTS: LSP10
RX: LSP10
SW1: Reset; B3F-10XX
TX: LSP10

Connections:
+3V3: MDL1.8 (VCC), R6.1, R7.1, R8.1, R9.1
CH_PD: MDL1.3 (CH_PD), R6.2
D2: MDL1.14 (GPIO5)
D5: MDL1.5 (GPIO14), RAIN1.MP
DTR: DTR.MP, Q2.2 (E), R3.1
GND: MDL1.9 (GND), RAIN2.MP, SW1.3
GNDA: GND_.MP, R10.1
GPIO0: MDL1.12 (GPIO0), Q2.3 (C), R8.2
GPIO2: MDL1.11 (GPIO2), R9.2
GPIO15: MDL1.10 (GPIO15), R10.2
unnamed: R1.1, RX.MP
unnamed: R2.1, TX.MP
unnamed: Q1.1 (B), R3.2
unnamed: Q2.1 (B), R4.2
RST: MDL1.1 (REST), Q1.2 (E), R7.2, SW1.1 (S)
RTS: Q1.3 (C), R4.1, RTS.MP
RX: MDL1.16 (TXD), R1.2
TX: MDL1.15 (RXD), R2.2

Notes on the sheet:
Sensor de Chuva
Microcontrolador ESP8266
FDTI


Board: 2 copper layers, 47.3 x 80.0 mm, 20 parts (1 on the bottom side), 17 nets.

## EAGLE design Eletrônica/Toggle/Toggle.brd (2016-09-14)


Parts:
BUT: M021X02_NO_SILK; 1X02_NO_SILK
C1, C2: 10uF 10V; C0805
D1: DIODESOD523; SOD523
D5: DB2S31600; SMA-DIODE
JP1: M021X02_NO_SILK; 1X02_NO_SILK
JP3: M031X03_NO_SILK; 1X03_NO_SILK
Q1: PFET; MICRO3
Q2: NFET; SOT23
R1: 10k; R0603
R2, R4: 1M; R0603
R3: 0R; R0603
R5, R6: 100R; R0603

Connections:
ARD_OFF: D1.C, JP3.3, R2.1, R3.2
BUTTONS: Q1.1 (G), Q2.3 (D), R1.1, R5.1
GND: C1.2, C2.2, JP1.1, JP3.1, Q2.2 (S), R4.1, R6.1
unnamed: C2.1, D1.A, Q2.1 (G), R3.1, R4.2
unnamed: BUT.2, R5.2
unnamed: D5.A, Q1.3 (D), R2.2
unnamed: BUT.1, R6.2
VIN: JP1.2, Q1.2 (S), R1.2
VOUT: C1.1, D5.C, JP3.2

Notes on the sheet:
e.g.: IRLML6402, IRLML5203, etc
To Arduino, NRF24, etc..
To turn off: DigitalWrite(6, LOW);
From Battery
Power Toggle


Board: 2 copper layers, 15.2 x 15.2 mm, 15 parts (0 on the bottom side), 9 nets.

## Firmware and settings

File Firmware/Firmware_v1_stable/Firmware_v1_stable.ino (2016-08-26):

#include <DHT.h>
#include <ESP8266WiFi.h>
#include <WiFiManager.h>
#include <DNSServer.h>

//Pins used in NODEMCU
#define DHTPIN_1 D7 // pin where the dht22 is connected
#define hall_pin D4

//Thingspeak variables
String apiKey = "P311PRHCHMLDI8Z7";
const char* server = "api.thingspeak.com";

//// Wifi connection variables
WiFiClient client;

//General variables
unsigned long time_passed = 0;
unsigned long time_passed_0 = 0;
unsigned long last_time_passed = 0;

//DHT22 Variables
volatile float h;
volatile float t;
volatile float hic;
DHT dht1(DHTPIN_1, DHT22,20);


//Tipping Bucket Variables
const float area = 6313.0; //Contribuition area in mm²
const float calibrated_vol = 2.2; //Bucket Calibrated Volume in ml
volatile float tipcount = 0;
volatile float last_tipcount = 0;
float rain = 0;
int real_tipcount = 0;
unsigned long lastmillis = 0;


//Function for reading DHT22
void ReadDHTSensor_1(){
  h = dht1.readHumidity();
  t = dht1.readTemperature();
  hic = dht1.computeHeatIndex(t, h, false);
  if (isnan(h) || isnan(t)) {
    Serial.println("Failed to read from DHT sensor!");
    return;
  }
  h = dht1.readHumidity();
  t = dht1.readTemperature();
  hic = dht1.computeHeatIndex(t, h, false);
  
     Serial.println("Sensor_1");
     Serial.print("Temperature: ");
     Serial.print(t);
     Serial.print(" degrees Celcius, Humidity: ");
     Serial.print(h);
     Serial.println("%. Send to Thingspeak.");
     Serial.print("Feelslike:");
     Serial.print(hic);
     Serial.println(" degrees Celcius.");
     Serial.println("Waiting...");
}

//Function for sending data to Thingspeak
void connect2wifi_send(){
  if (client.connect(server,80)) {  //   "184.106.153.149" or api.thingspeak.com
    String postStr = apiKey;
           postStr +="&field1=";
           postStr += String(t);
           postStr +="&field2=";
           postStr += String(h);
           postStr +="&field3=";
           postStr += String(hic);
           postStr +="&field4=";
           postStr += String(rain);
           postStr += "\r\n\r\n";
           
     client.print("POST /update HTTP/1.1\n");
     client.print("Host: api.thingspeak.com\n");
     client.print("Connection: close\n");
     client.print("X-THINGSPEAKAPIKEY: "+apiKey+"\n");
     client.print("Content-Type: application/x-www-form-urlencoded\n");
     client.print("Content-Length: ");
     client.print(postStr.length());
     client.print("\n\n");
     client.print(postStr);
     client.stop(); 
  }
}
//Function for counting Tips
void tip_fan(){ 
  tipcount++;
 //Serial.println(tipcount);
}

void setup() {
  
  //Initializing DHT22 Sensor
  dht1.begin();
  //Serial Communication for DEBUG
  Serial.begin(115200);
  Serial.println("###### Warm up ######");
  WiFiManager wifiManager;
  wifiManager.autoConnect();
  Serial.println("Connected...");
  ReadDHTSensor_1();
  connect2wifi_send();
  last_time_passed = time_passed;
  attachInterrupt(hall_pin, tip_fan, CHANGE);
}

void loop() {
  time_passed_0 = millis();
  if ((time_passed_0 - lastmillis) >= 1000){  //Debouncing strategy
   detachInterrupt(D4);    //Disable interrupt when calculating
   if (tipcount > last_tipcount){
    real_tipcount++;
    last_tipcount = tipcount;
    rain = real_tipcount * calibrated_vol*1000/area;  /* Convert tip into mm*/
    connect2wifi_send();
   }
//   Serial.print("Tips: ");
//   Serial.println(rain);
   lastmillis = millis(); // Uptade lasmillis
   attachInterrupt(D4, tip_fan, CHANGE); //enable interrupt
  }
  
  time_passed = millis();
  if ((time_passed - last_time_passed) >= 1800000) {
    ReadDHTSensor_1();
    connect2wifi_send();
    last_time_passed = time_passed;
    return;
  }
}

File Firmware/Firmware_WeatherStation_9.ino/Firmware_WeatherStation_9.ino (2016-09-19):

//filesystem
#include <FS.h>                   //this needs to be first, or it all crashes and burns...



// to make an unique ID
// __TIME__
// https://gcc.gnu.org/onlinedocs/cpp/Standard-Predefined-Macros.html


////////////////////////////////////////////////////////
// debug defines
// you may frown upon preprocessor directives ;-)
#define DEBUG_ENABLED true

#if DEBUG_ENABLED
#define DEBUG(text) { Serial.println ( (text) ); }
#else
#define DEBUG(text) {}
#endif
// end DEBUG(text)

#if DEBUG_ENABLED
#define DEBUG_SETUP(baudrate) { Serial.begin( (baudrate) ); }
#else
#define DEBUG_SETUP(baudrate) {}
#endif
// end DEBUG_SETUP(baudrate)
////////////////////////////////////////////////////////

#include <DHT.h>
#include <ESP8266WiFi.h>
#include <WiFiManager.h>
#include <DNSServer.h>
// to save custom parameters
#include <ArduinoJson.h>          //https://github.com/bblanchon/ArduinoJson

//Pins used in NODEMCU
#define DHTPIN_1 D1 // pin where the dht22 is connected
#define hall_pin D2
ADC_MODE(ADC_VCC); // debug voltage in

//Thingspeak variables
String apiKey = "P311PRHCHMLDI8Z7";
const char* server = "api.thingspeak.com";

//// Wifi connection variables
WiFiClient client;

//define your default values here, if there are different values in config.json, they are overwritten.
char geo_code[40];

//flag for saving data
bool shouldSaveConfig = false;

//General variables
unsigned long time_passed = 0;
unsigned long time_passed_0 = 0;
unsigned long last_time_passed = 0;
unsigned long zerador = 0;
volatile int chuva_status = 0;

//DHT22 Variables
volatile float h;
volatile float t;
volatile float hic;
DHT dht1(DHTPIN_1, DHT22, 20);


//Tipping Bucket Variables
const float area = 6313.0; //Contribuition area in mm²
const float calibrated_vol = 2.2; //Bucket Calibrated Volume in ml
volatile float tipcount = 0;
volatile float last_tipcount = 0;
float rain = 0;
int real_tipcount = 0;
unsigned long lastmillis = 0;


//Function for reading DHT22
void ReadDHTSensor_1() {
  h = dht1.readHumidity();
  t = dht1.readTemperature();
  hic = dht1.computeHeatIndex(t, h, false);
  if (isnan(h) || isnan(t)) {
    DEBUG("Failed to read from DHT sensor!");
    return;
  }
  DEBUG("Sensor_1");
  DEBUG("Temperature: ");
  DEBUG(t);
  DEBUG(" degrees Celsius, Humidity: ");
  DEBUG(h);
  DEBUG("%. Send to Thingspeak.");
  DEBUG("Feelslike:");
  DEBUG(hic);
  DEBUG(" degrees Celsius.");
  // doesn't need to divide
  DEBUG(ESP.getVcc() / 1000.000);
  DEBUG("Waiting...");
}

//Function for sending data to Thingspeak
void connect2wifi_send() {
  if (client.connect(server, 80)) { //   "184.106.153.149" or api.thingspeak.com
    String postStr = apiKey;
    postStr += "&field1=";
    postStr += String(t);
    postStr += "&field2=";
    postStr += String(h);
    postStr += "&field3=";
    postStr += String(hic);
    postStr += "&field4=";
    postStr += String(rain);
    postStr += "&field5=";
    postStr += String(ESP.getVcc() / 1000.000);
    postStr += "&field6=";
    postStr += String(chuva_status);
    postStr += "\r\n\r\n";

    client.print("POST /update HTTP/1.1\n");
    client.print("Host: api.thingspeak.com\n");
    client.print("Connection: close\n");
    client.print("X-THINGSPEAKAPIKEY: " + apiKey + "\n");
    client.print("Content-Type: application/x-www-form-urlencoded\n");
    client.print("Content-Length: ");
    client.print(postStr.length());
    client.print("\n\n");
    client.print(postStr);
    client.stop();
  }
}
//Function for counting Tips
void tip_fan() {
  tipcount++;
  //DEBUG(tipcount);
}

void chuva_on() {
#if DEBUG_ENABLED
  DEBUG("Ta chuveno");
  DEBUG(digitalRead(D2));
#endif
  chuva_status  = 1;
  detachInterrupt(D2);    //Disable interrupt when calculating

}


void setup() {

  //Serial Communication for DEBUG
  DEBUG_SETUP(115200);
  DEBUG("###### Warm up ######");
  DEBUG(ESP.getResetReason());
  DEBUG(ESP.getChipId());

  //Initializing DHT22 Sensor
  dht1.begin();


  // The extra parameters to be configured (can be either global or just in the setup)
  // After connecting, parameter.getValue() will get you the configured value
  // id/name placeholder/prompt default length
  WiFiManagerParameter custom_geo("geo", "geo code", geo_code, 40);

  //WiFiManager
  //Local intialization. Once its business is done, there is no need to keep it around
  WiFiManager wifiManager;

  //set config save notify callback
  wifiManager.setSaveConfigCallback(saveConfigCallback);

  //add all your parameters here
  wifiManager.addParameter(&custom_geo);

  wifiManager.autoConnect();

  DEBUG("Connected...");


  //////////////////////////////////////////////
// aqui vai o codigo pra ler e gravar no filesystem, de acordo com o exemplo 
// AutoConnectWithFSParameters.ino
  //////////////////////////////////////////////

  ReadDHTSensor_1();
  connect2wifi_send();
  last_time_passed = time_passed;
  attachInterrupt(hall_pin, tip_fan, CHANGE);
  attachInterrupt(D2, chuva_on, CHANGE);
  //pinMode(D2,INPUT);

}

void loop() {
  time_passed_0 = millis();
  if ((time_passed_0 - lastmillis) >= 1000) { //Debouncing strategy
    detachInterrupt(hall_pin);    //Disable interrupt when calculating
    if (tipcount > last_tipcount) {
      real_tipcount++;
      last_tipcount = tipcount;
      rain = real_tipcount * calibrated_vol * 1000 / area; /* Convert tip into mm*/
      connect2wifi_send();
    }

    //   DEBUG("Tips: ");
    //   DEBUG(rain);
    lastmillis = millis(); // Update lasmillis
    attachInterrupt(hall_pin, tip_fan, CHANGE); //enable interrupt
  }

  time_passed = millis();
  if ((time_passed - last_time_passed) >= 1800000) { //read DHT22 every 30 min
    ReadDHTSensor_1();
    connect2wifi_send();
    last_time_passed = time_passed;
    zerador++;
    return;
  }
  // "zero" rain counter every 24 hours
  if (zerador == 48) {
    tipcount = 0;
    last_tipcount = 0;
    rain = 0;
    real_tipcount = 0;
    zerador = 0;
  }
  if (chuva_status == 1) {
    pinMode(D2, INPUT);
    if (digitalRead(D2) == 1) {
      DEBUG("Parou de chover");
      chuva_status  = 0;
      attachInterrupt(D2, chuva_on, CHANGE);
    }
  }
}

//callback notifying us of the need to save config
void saveConfigCallback () {
  DEBUG("Should save config");
  shouldSaveConfig = true;
}

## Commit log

2016-09-13 .DS_Store Cleanup
    [Toggle.brd, Toggle.sch]
2016-09-13 Eagle .gitignore updates
    [Toggle.brd, Toggle.sch]
2016-09-14 1st commit
    [pluvionV0.brd, pluvionV0.sch]
2016-09-14 Update schematic
    [pluvionV0.brd, pluvionV0.sch]
2016-09-14 Toggle updated
    [Pluvion 1 - Rev A.brd, Pluvion 1 - Rev A.sch, Toggle.brd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]
2016-09-14 Eagle files
    [pluvionV0.brd, pluvionV0.sch]
2016-09-14 Eagle Rev A
    [Bucket.SLDPRT, Bucket.STL, ESP8266 + Serial Programming.brd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]
2016-09-14 Prototype BOM
    [Pluvion 1 - Rev A.brd, Pluvion 1 - Rev A.sch]
2016-09-14 Gerber Files
    [Pluvion 1 - Rev A.brd]
2016-09-19 Firmware com mudanças e funcionalidades novas
    [Pluvion 1 - Rev A.brd]
2016-09-22 Pluvion Rev B for tests
    [Pluvion 1 - Rev B.brd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]
2016-09-22 Pluvion 1 Rev C
    [Pluvion 1 - Rev A.brd, Pluvion 1 - Rev A.sch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]
2016-09-22 Pluvion V2
    [Pluvion 2.brd, Pluvion 2.sch]
2016-09-22 Adding schematic images
    [Pluvion 2 - vPG.brd, Pluvion 2 - vPG.sch]
2016-09-22 Inclusao de montagem mecanica
    [Base.stl, Montagem Pluvi.on - SW.SLDPRT, Montagem Pluvi.on - SW.STL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]
2016-09-24 Pluvion V2 ready for prototyping
    [Pluvion 2.brd, Pluvion 2.sch]
2016-09-29 Shield Update
    [Pluvion 2 - Rev A.brd, Pluvion 2 - Rev A.sch, Pluvion 2 - Rev B.brd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]

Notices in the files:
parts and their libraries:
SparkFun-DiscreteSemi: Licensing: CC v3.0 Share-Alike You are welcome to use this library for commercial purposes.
